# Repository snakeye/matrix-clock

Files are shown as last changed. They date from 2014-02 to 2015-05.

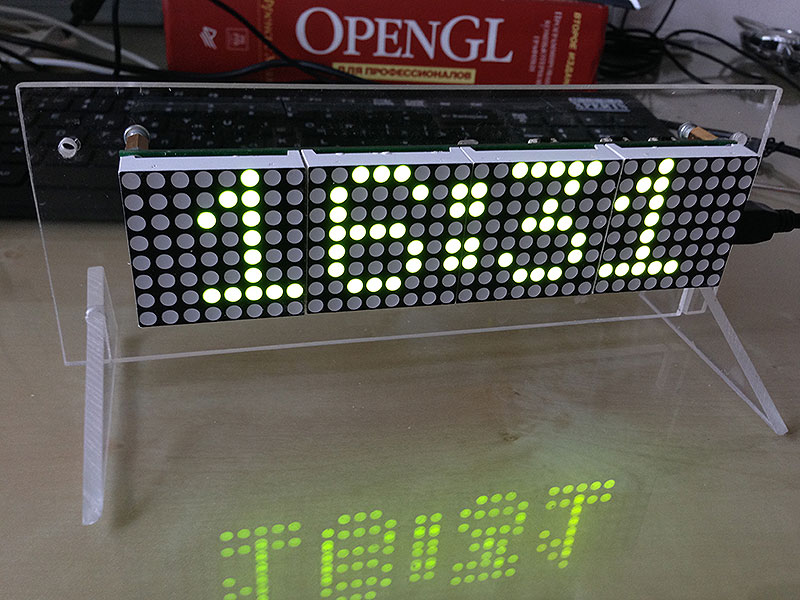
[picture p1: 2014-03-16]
pictures/pic3.jpg

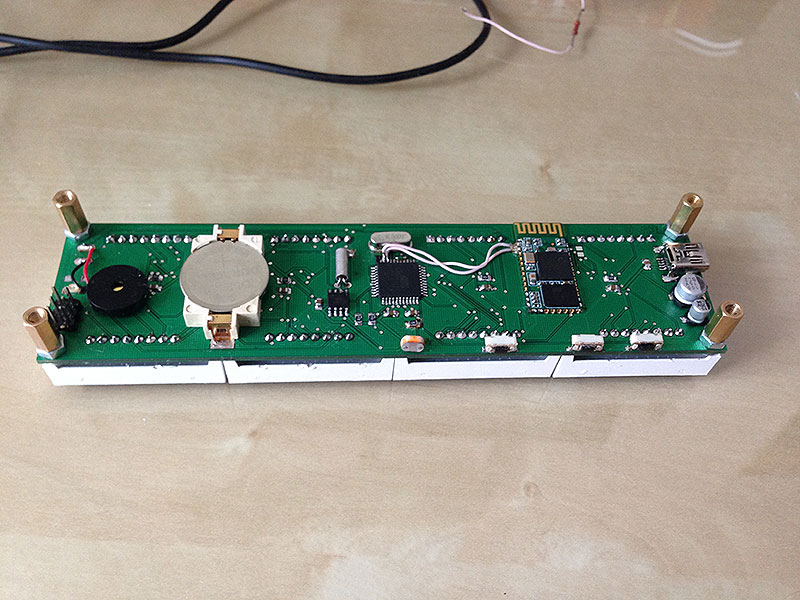
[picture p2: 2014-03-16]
pictures/pic2.jpg

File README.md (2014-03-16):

Matrix LED Clock
============

The goal of this project is to make nice bedroom clock with 8x8 LED matrices.

Features:

* 8x8 Common Cathode **LED matrices**
* **ATMega32** microcontroller
* **DS1307** realtime clock
* **MAX7219** display drivers
* **HC-05** bluetooth module
* Ambient **light sensor**

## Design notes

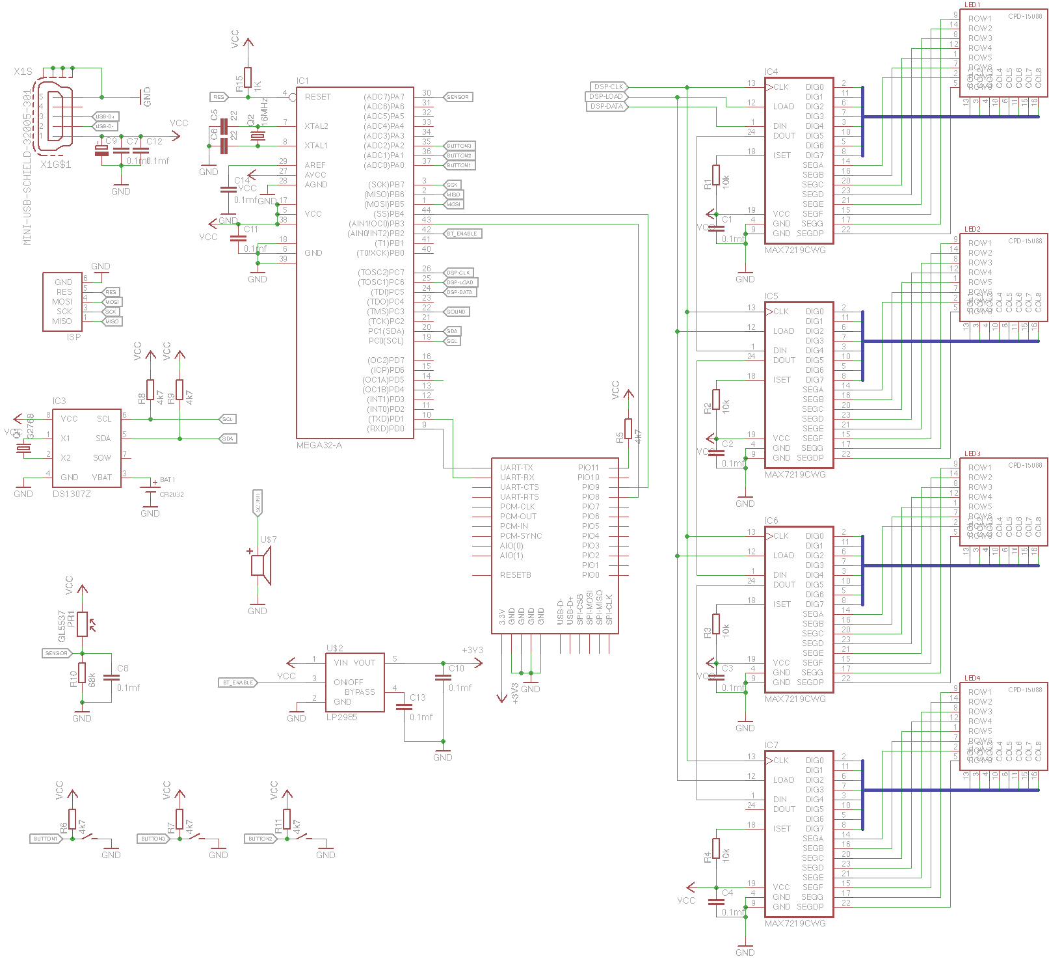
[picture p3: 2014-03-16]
Schematic Rev B.png

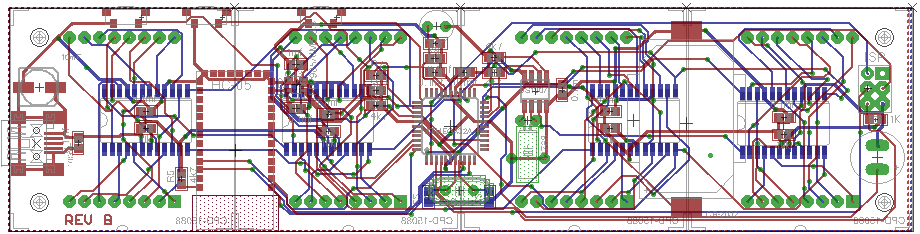
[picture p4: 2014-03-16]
Board Rev B.png

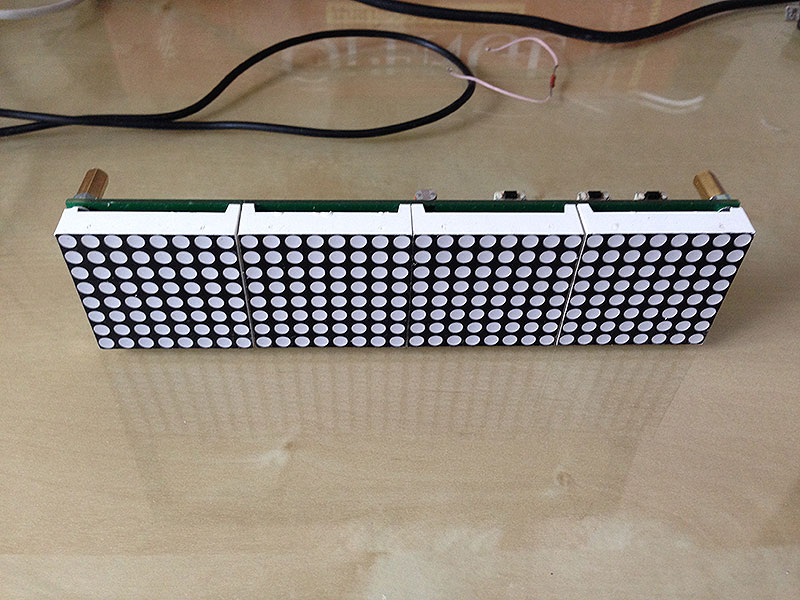
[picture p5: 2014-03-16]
pictures/pic1.jpg

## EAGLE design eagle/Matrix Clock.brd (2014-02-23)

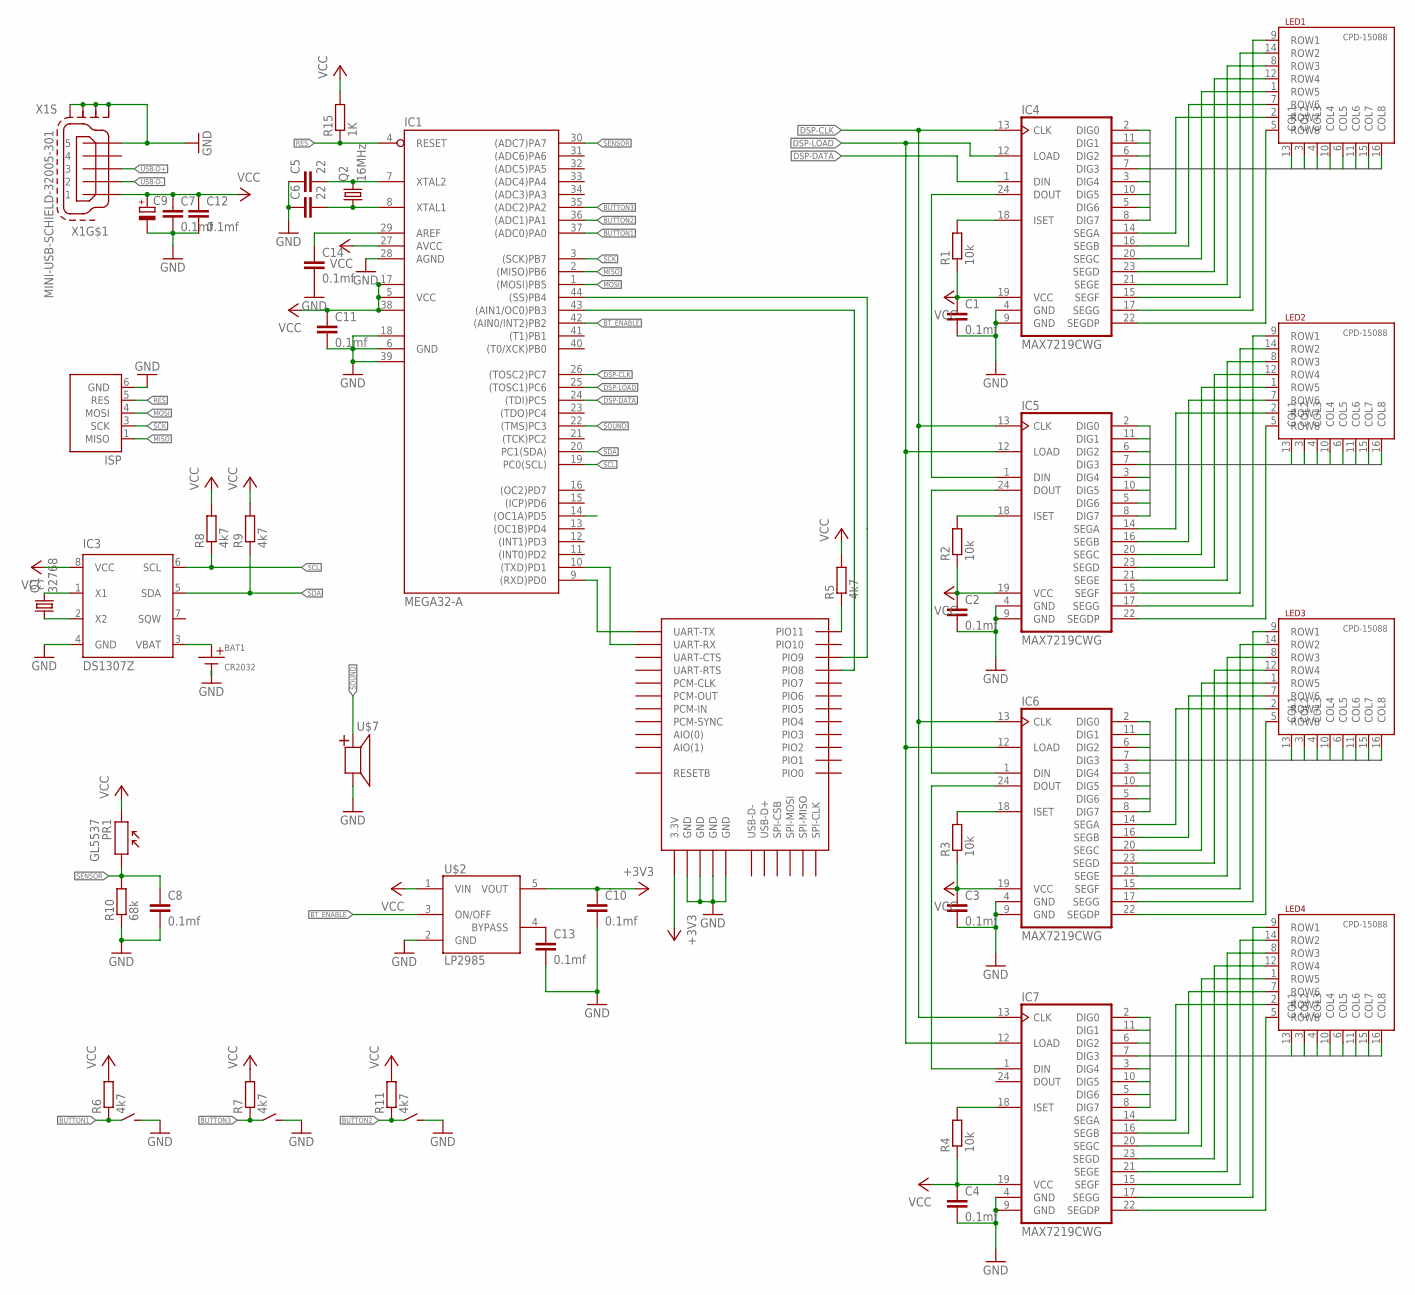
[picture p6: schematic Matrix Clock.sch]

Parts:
BAT1: CR2032; CR2032-SMD
C1, C2, C3, C4, C7, C8, C10, C11, C12, C13, C14: 0.1mf; C0805
C5, C6: 22; C0805
C9: CPOL-EU153CLV-0605; 153CLV-0605
IC1: MEGA32-A; TQFP44
IC3: DS1307Z; SOIC8
IC4, IC5, IC6, IC7: MAX7219CWG; SO24L
LED1, LED2, LED3, LED4: CPD-15088YGD2/A; CPD15088
PR1: GL5537; GL55
Q1: 32768; TC38H
Q2: 16MHz; HC49/S
R1, R2, R3, R4: 10k; R0805
R5, R6, R7, R8, R9, R11: 4k7; R0805
R10: 68k; R0805
R15: 1K; R0805
U$1: BTM400_6B
U$2: LP2985AIM5-3.3; SOT25
U$3: AVR-ISP
U$7: HC0905
U$9, U$10, U$11: IT1188E
X1: MINI-USB-SCHIELD-32005-301; 32005-301

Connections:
+3V3: C10.1, U$1.3.3V, U$2.5 (VOUT)
BT_ENABLE: IC1.42 ((AIN0/INT2)PB2), U$2.3 (ON/OFF)
BUTTON1: IC1.37 ((ADC0)PA0), R6.1, U$9.3
BUTTON2: IC1.36 ((ADC1)PA1), R11.1, U$10.3
BUTTON3: IC1.14 ((OC1A)PD5), IC1.35 ((ADC2)PA2), R7.1, U$11.3
BYPASS: C13.1, U$2.4 (BYPASS)
C0: IC4.2 (DIG0), LED1.13 (COL1)
C1: IC4.11 (DIG1), LED1.3 (COL2)
C2: IC4.6 (DIG2), LED1.4 (COL3)
C3: IC4.7 (DIG3), LED1.10 (COL4)
C4: IC4.3 (DIG4), LED1.6 (COL5)
C5: IC4.10 (DIG5), LED1.11 (COL6)
C6: IC4.5 (DIG6), LED1.15 (COL7)
C7: IC4.8 (DIG7), LED1.16 (COL8)
C8: IC5.2 (DIG0), LED2.13 (COL1)
C9: IC5.11 (DIG1), LED2.3 (COL2)
C10: IC5.6 (DIG2), LED2.4 (COL3)
C11: IC5.7 (DIG3), LED2.10 (COL4)
C12: IC5.3 (DIG4), LED2.6 (COL5)
C13: IC5.10 (DIG5), LED2.11 (COL6)
C14: IC5.5 (DIG6), LED2.15 (COL7)
C15: IC5.8 (DIG7), LED2.16 (COL8)
C16: IC6.2 (DIG0), LED3.13 (COL1)
C17: IC6.11 (DIG1), LED3.3 (COL2)
C18: IC6.6 (DIG2), LED3.4 (COL3)
C19: IC6.7 (DIG3), LED3.10 (COL4)
C20: IC6.3 (DIG4), LED3.6 (COL5)
C21: IC6.10 (DIG5), LED3.11 (COL6)
C22: IC6.5 (DIG6), LED3.15 (COL7)
C23: IC6.8 (DIG7), LED3.16 (COL8)
C24: IC7.2 (DIG0), LED4.13 (COL1)
C25: IC7.11 (DIG1), LED4.3 (COL2)
C26: IC7.6 (DIG2), LED4.4 (COL3)
C27: IC7.7 (DIG3), LED4.10 (COL4)
C28: IC7.3 (DIG4), LED4.6 (COL5)
C29: IC7.10 (DIG5), LED4.11 (COL6)
C30: IC7.5 (DIG6), LED4.15 (COL7)
C31: IC7.8 (DIG7), LED4.16 (COL8)
DSP-CLK: IC1.26 ((TOSC2)PC7), IC4.13 (CLK), IC5.13 (CLK), IC6.13 (CLK), IC7.13 (CLK)
DSP-DATA: IC1.24 ((TDI)PC5), IC4.1 (DIN)
DSP-LOAD: IC1.25 ((TOSC1)PC6), IC4.12 (LOAD), IC5.12 (LOAD), IC6.12 (LOAD), IC7.12 (LOAD)
GND: BAT1.- (GND), C1.2, C2.2, C3.2, C4.2, C5.1, C6.1, C7.2, C8.2, C9.-, C10.2, C11.2, C12.2, C13.2, C14.2, IC1.6 (GND), IC1.18 (GND1), IC1.28 (AGND), IC1.39 (GND2), IC3.4 (GND), IC4.4 (GND), IC4.9 (GND), IC5.4 (GND), IC5.9 (GND), IC6.4 (GND), IC6.9 (GND), IC7.4 (GND), IC7.9 (GND), R10.1, U$1.GND@1 (GND), U$1.GND@2 (GND), U$1.GND@3 (GND), U$1.GND@4 (GND), U$2.2 (GND), U$3.6 (GND), U$7.P$1, U$9.4, U$10.4, U$11.4, X1.5, X1.M1 (S1), X1.M2 (S2), X1.M3 (S3), X1.M4 (S4)
MISO: IC1.2 ((MISO)PB6), U$3.1 (MISO)
MOSI: IC1.1 ((MOSI)PB5), U$3.4 (MOSI)
unnamed: IC4.22 (SEGDP), LED1.5 (ROW8)
unnamed: IC4.18 (ISET), R1.2
unnamed: BAT1.+ (VBAT), IC3.3 (VBAT)
unnamed: IC1.10 ((TXD)PD1), U$1.UART-RX
unnamed: IC1.9 ((RXD)PD0), U$1.UART-TX
unnamed: IC4.17 (SEGG), LED1.9 (ROW1)
unnamed: IC4.15 (SEGF), LED1.14 (ROW2)
unnamed: IC4.21 (SEGE), LED1.8 (ROW3)
unnamed: IC4.23 (SEGD), LED1.12 (ROW4)
unnamed: IC4.20 (SEGC), LED1.1 (ROW5)
unnamed: IC4.16 (SEGB), LED1.7 (ROW6)
unnamed: IC4.14 (SEGA), LED1.2 (ROW7)
unnamed: IC5.18 (ISET), R2.2
unnamed: IC5.24 (DOUT), IC6.1 (DIN)
unnamed: IC6.24 (DOUT), IC7.1 (DIN)
unnamed: IC4.24 (DOUT), IC5.1 (DIN)
unnamed: IC5.22 (SEGDP), LED2.5 (ROW8)
unnamed: IC5.17 (SEGG), LED2.9 (ROW1)
unnamed: IC5.15 (SEGF), LED2.14 (ROW2)
unnamed: IC5.21 (SEGE), LED2.8 (ROW3)
unnamed: IC5.23 (SEGD), LED2.12 (ROW4)
unnamed: IC5.20 (SEGC), LED2.1 (ROW5)
unnamed: IC5.16 (SEGB), LED2.7 (ROW6)
unnamed: IC5.14 (SEGA), LED2.2 (ROW7)
unnamed: IC6.18 (ISET), R3.2
unnamed: IC1.44 ((SS)PB4), U$1.PIO(9) (PIO9)
unnamed: IC1.43 ((AIN1/OC0)PB3), U$1.PIO(8) (PIO8)
unnamed: R5.1, U$1.PIO(11) (PIO11)
unnamed: IC6.22 (SEGDP), LED3.5 (ROW8)
unnamed: IC6.17 (SEGG), LED3.9 (ROW1)
unnamed: IC6.15 (SEGF), LED3.14 (ROW2)
unnamed: IC6.21 (SEGE), LED3.8 (ROW3)
unnamed: IC6.23 (SEGD), LED3.12 (ROW4)
unnamed: IC6.20 (SEGC), LED3.1 (ROW5)
unnamed: IC6.16 (SEGB), LED3.7 (ROW6)
unnamed: IC6.14 (SEGA), LED3.2 (ROW7)
unnamed: IC7.18 (ISET), R4.2
unnamed: IC7.22 (SEGDP), LED4.5 (ROW8)
unnamed: IC7.17 (SEGG), LED4.9 (ROW1)
unnamed: IC7.15 (SEGF), LED4.14 (ROW2)
unnamed: IC7.21 (SEGE), LED4.8 (ROW3)
unnamed: IC7.23 (SEGD), LED4.12 (ROW4)
unnamed: IC7.20 (SEGC), LED4.1 (ROW5)
unnamed: IC7.16 (SEGB), LED4.7 (ROW6)
unnamed: IC7.14 (SEGA), LED4.2 (ROW7)
unnamed: IC3.1 (X1), Q1.2
unnamed: IC3.2 (X2), Q1.1
unnamed: C14.1, IC1.29 (AREF)
RES: IC1.4 (RESET), R15.1, U$3.5 (RES)
SCK: IC1.3 ((SCK)PB7), U$3.3 (SCK)
SCL: IC1.19 (PC0(SCL)), IC3.6 (SCL), R8.1
SDA: IC1.20 (PC1(SDA)), IC3.5 (SDA), R9.1
SENSOR: C8.1, IC1.30 ((ADC7)PA7), PR1.P$2, R10.2
SOUND: IC1.22 ((TMS)PC3), U$7.P$2
USB-D+: X1.3
USB-D-: X1.2
VCC: C1.1, C2.1, C3.1, C4.1, C7.1, C9.+, C11.1, C12.1, IC1.5 (VCC), IC1.17 (VCC1), IC1.27 (AVCC), IC1.38 (VCC2), IC3.8 (VCC), IC4.19 (VCC), IC5.19 (VCC), IC6.19 (VCC), IC7.19 (VCC), PR1.P$1, R1.1, R2.1, R3.1, R4.1, R5.2, R6.2, R7.2, R8.2, R9.2, R11.2, R15.2, U$2.1 (VIN), X1.1
XTAL1: C6.2, IC1.8 (XTAL1), Q2.1
XTAL2: C5.2, IC1.7 (XTAL2), Q2.2

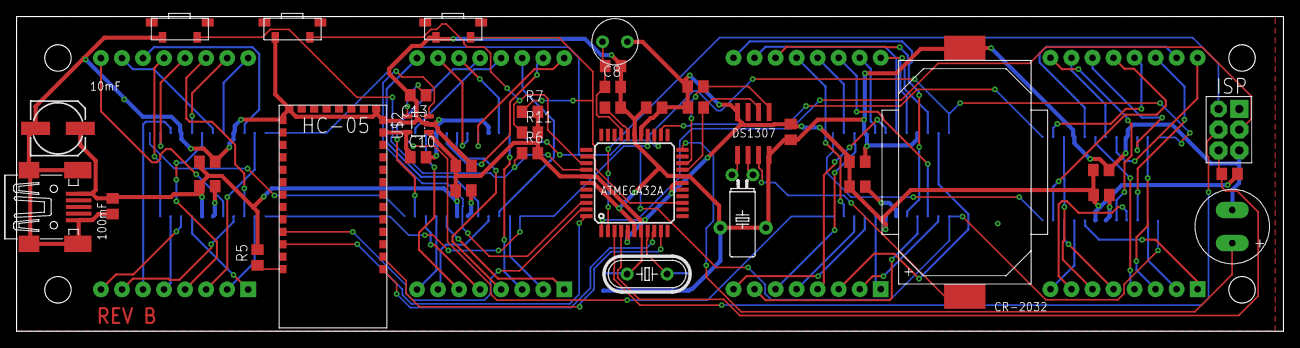
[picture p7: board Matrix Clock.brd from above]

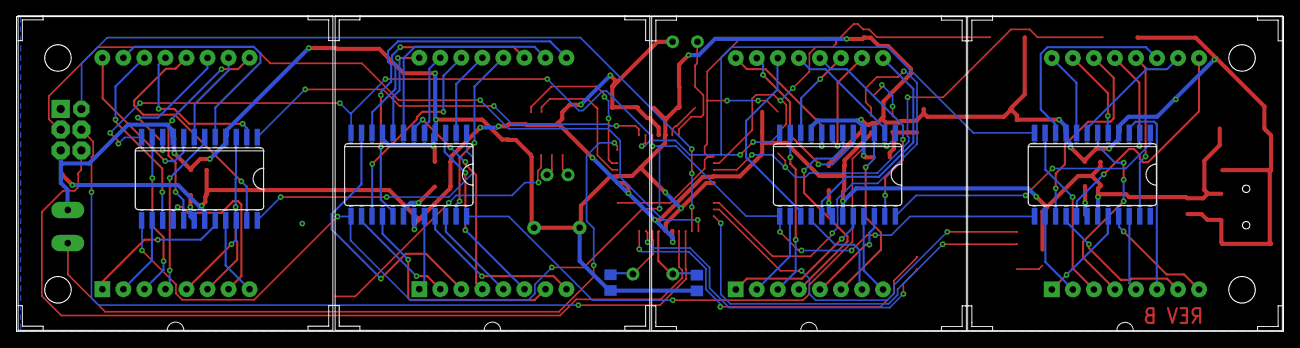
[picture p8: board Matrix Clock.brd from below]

Board: 2 copper layers, 153.0 x 38.0 mm, 48 parts (10 on the bottom side), 101 nets.

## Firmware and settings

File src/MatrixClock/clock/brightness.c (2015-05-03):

/*
* brightness.c
*
* Created: 24.01.2014 22:59:26
*  Author: snakeye
*/
#include <avr/io.h>
#include <avr/interrupt.h>

#include "settings.h"
#include "../lib/display.h"

#define HISTORY_LENGTH 20

uint16_t brightness_history[HISTORY_LENGTH] = {0};
uint8_t brightness_ptr = 0;

uint16_t brightness = 0x8;

/**
* ADC Interrupt handler
*/
ISR(ADC_vect)
{
	uint16_t br = (ADCL | (ADCH << 8));
	brightness_history[brightness_ptr] = br;
	brightness_ptr = (brightness_ptr + 1) % HISTORY_LENGTH;
	
	br = 0;
	for(uint8_t i = 0; i < HISTORY_LENGTH; i++) {
		br += brightness_history[i];		
	}
	
	// average
	brightness = br / HISTORY_LENGTH;
}

void adc_init()
{
	// init ADC
	// VCC with capacitor on AREF
	// ADC7 as source
	ADMUX = (1 << REFS0) | (0b111);
	// ADC enable
	// prescale = 128
	// interrupt enable
	ADCSRA = (1 << ADEN) | (1 << ADPS2) | (1 << ADPS1) | (1 << ADPS0)  | (1 << ADIE);
}

/**
* Start ADC conversion
*/
void measure_brightness_async()
{
	ADCSRA |= (1 << ADSC);
}

/**
 * 
 */
uint16_t measure_brightness_sync()
{
	ADCSRA |= (1 << ADSC);
	
	// wait for conversion finished
	//while(){
	//}
	
	//
	brightness = (ADCL | (ADCH << 8));

	return brightness;
}

/**
 * 
 */
void brightness_tick()
{
	static uint8_t tick = 0;

	tick++;
	if(tick >= 250) {
		tick = 0;
		
		if(settings.brightness_auto) {
			//
			uint8_t b = (brightness * (settings.brightness_max - settings.brightness_min)) / 1024 + settings.brightness_min;
			display_set_brightness(b);
			
			//
			measure_brightness_async();
		}
	}
}

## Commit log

2013-12-09 REV A
    [Matrix Clock.brd, Matrix Clock.sch]
2014-01-19 Started clock firmware
    [Matrix Clock.brd, Matrix Clock.sch]
2014-01-24 Draw string function
    - Draw string function
    - Interrupt based brightness handling
    - Small charset update
2014-01-24 Brightness measurement
    - Added placeholders for peripheral devices
    - Added int to string conversion function
2014-01-25 Big update
    - Asyncronous USART operations
    - Asyncronous ADC
    - Updated schematics file and PCB
    [Matrix Clock.brd, Matrix Clock.sch]
2014-01-25 Added buttons processing
2014-01-26 REV A Beta 1
    Beta 1 Firmware for REV A board
2014-02-02 Fixed terminal response
    Fixed terminal response
    Added "Say" command
    [brightness.c]
2014-02-23 Updated schematics and board
    [Matrix Clock.brd, Matrix Clock.sch]
2014-03-16 Added schematic and board images, pictures of working clock
2014-05-18 UART module refactoring
2015-05-03 Added watchdog timer
